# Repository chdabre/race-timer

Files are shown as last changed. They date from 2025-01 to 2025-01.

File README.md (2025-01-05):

# ESP32 7-Segment Race Timer

[][cc-by-sa]

## Overview

A race timing system built with an ESP32-S3 microcontroller and LED display that measures elapsed time between start and finish sensors.

The connection box can provide power to multiple timer modules, and provides a reset button to reset all modules at once.

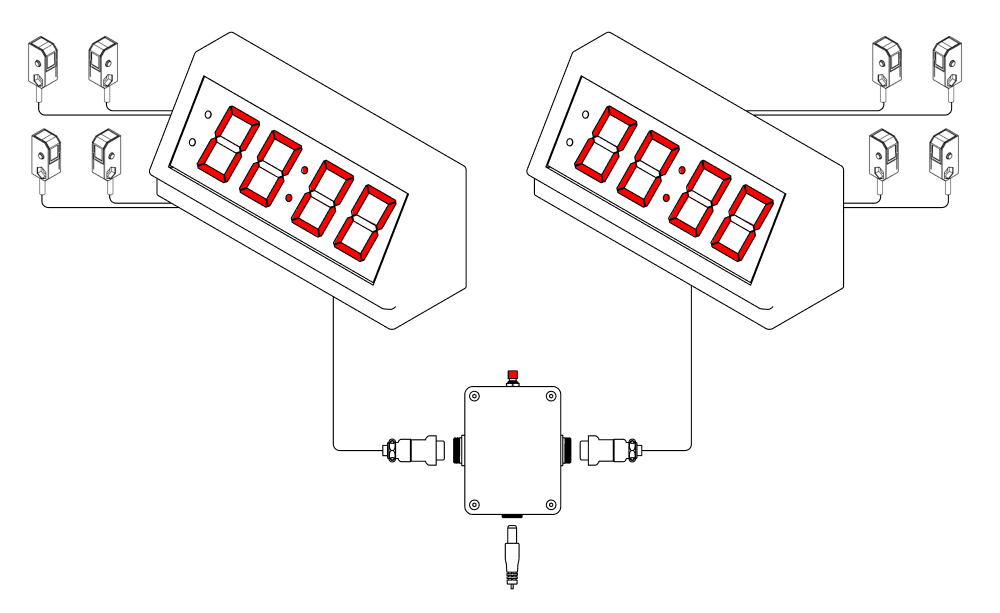
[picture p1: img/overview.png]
Timer Module


The system is designed to be easy to use and assemble. The timer modules are designed to be mounted to a table, and all wiring is run underneath the table.

The timer modules are connected to the connection box with a removable connector, so each module can be transported individually.

If more than 2 modules are needed, the connection box can be easily extended with additional connectors.

## Operation

Two light barriers are connected to each timer module, each consisting of a transmitter and receiver.

The START barrier is mounted at the beginning of the race track.
The STOP barrier is mounted at the end of the race track.

When the START barrier is interrupted, the current time measurement is reset and a new timing begins.

When the STOP barrier is interrupted while timing is active, the timing stops and the final time is shown on the display.

If a timing measurement exceeds 100 seconds, the time can no longer be fully displayed. The seconds display resets to 00: and timing continues.

When the RESET button is pressed at any time, the current timing is stopped and the display immediately resets to 00:00.

## Firmware development and flashing

The firmware is developed using the Arduino Platform on PlatformIO. The project is configured for the Adafruit ESP32-S3 Feather board.

### Dependencies

The following libraries are required and will be automatically installed by PlatformIO:

- Wire
- Adafruit LED Backpack Library

### Building and Flashing

1. Install VS Code and the PlatformIO extension
2. Clone this repository
3. Open the project folder in VS Code
4. Connect the Feather Board via USB
5. Click the PlatformIO "Upload" button or press Ctrl+Alt+U

The serial monitor can be opened at 115200 baud to view debug messages.

## Schematics

See also the KiCad project in the `hardware` folder.

**FeatherWing Schematic**
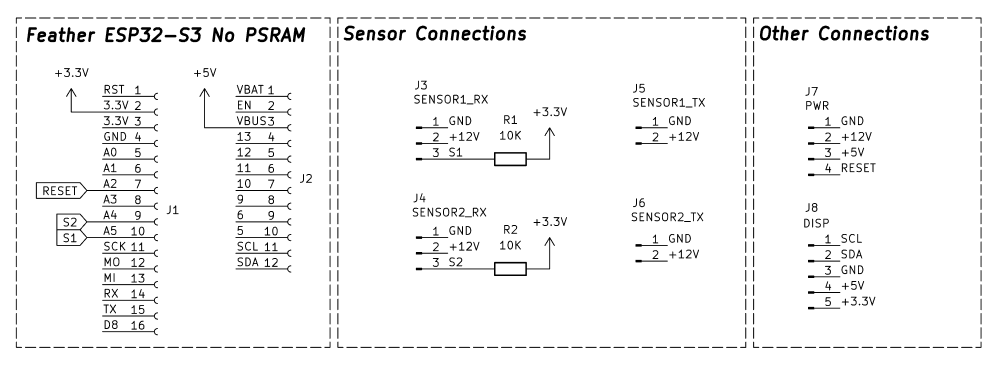
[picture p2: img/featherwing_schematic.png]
Schematic


**Connection Box Schematic**
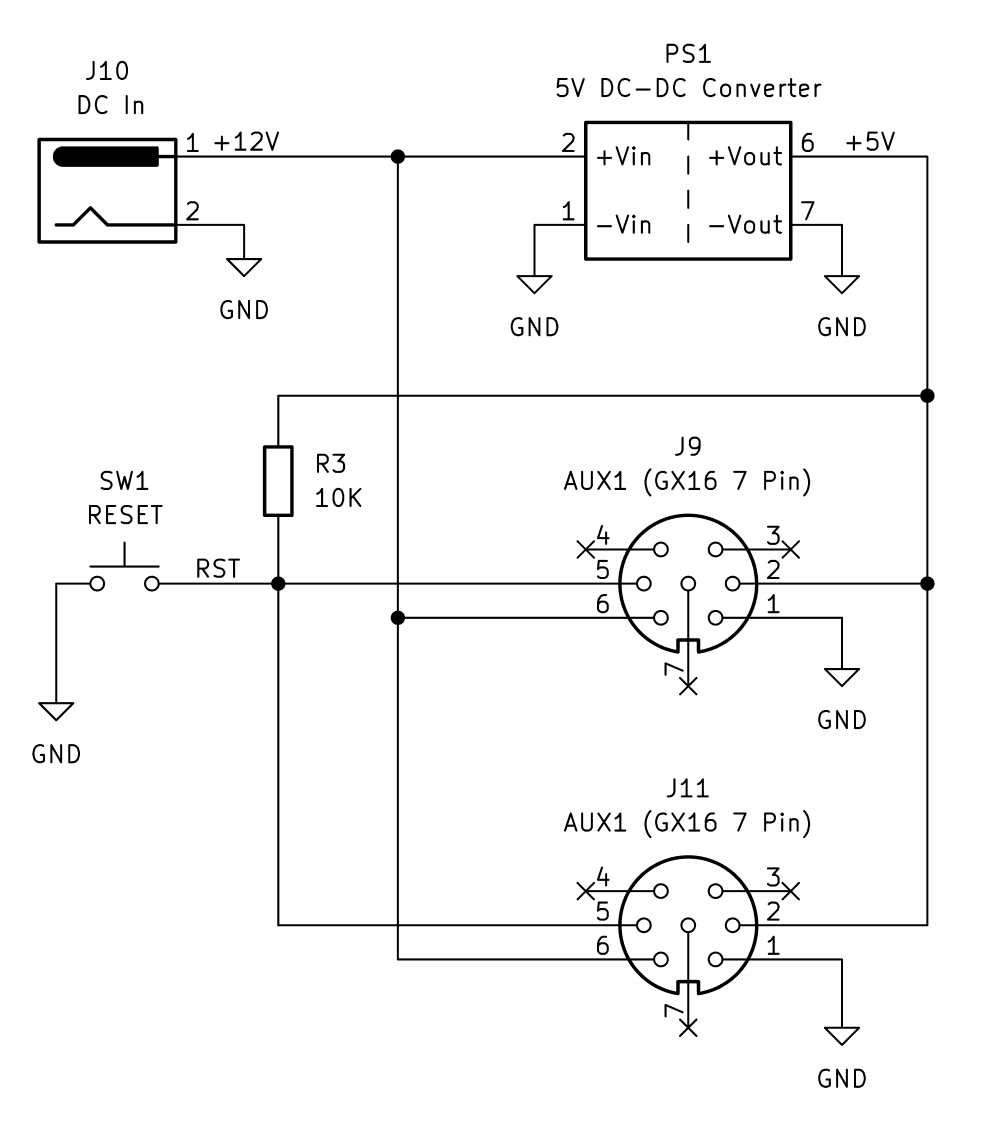
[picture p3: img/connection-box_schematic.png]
Connection Box Schematic


## Bill of Materials

**Per Timer Module**

- 1x 3d printed enclosure (See hardware folder)
- 4x M3 5mm threaded inserts
- 4x M4x6mm threaded inserts
- 4x M3x8mm hex screws
- 4x M4 mounting bolts
- 1x Adafruit ESP32-S3 Feather board (No PSRAM)
- 2x DFRobot Infrared Light Barrier Kit ([SEN0347](https://www.dfrobot.com/product-2057.html))
- 1x Race Timer FeatherWing (See hardware folder)
    - 1x Race Timer FeatherWing PCB 
    - 2x 16-Pin 2.54mm pin headers
    - 1x 5-Pin 2.54mm pin header
    - 2x JST-XH 2.50mm B2B (2-Pin)
    - 2x JST-XH 2.50mm B3B (3-Pin)
    - 1x JST-XH 2.50mm B4B (4-Pin)
    - 2x 10K 1/4W THT Resistor
- 2x JST-XH 2.50mm B2B (2-Pin) Female Connector
- 2x JST-XH 2.50mm B3B (3-Pin) Female Connector
- 1x JST-XH 2.50mm B4B (4-Pin) Female Connector
- 1x GX16 7-Pin Female Connector
- 4-core 20AWG cable to the connection box

**Connection Box**

- 1x 3d printed enclosure (See hardware folder)
- 4x M3 5mm threaded inserts
- 4x M3x8mm hex screws
- 1x Mini360 DC-DC Converter (or similar) 9-24V to 5V
- 2x GX16 7-Pin Male Connector
- 1x DC00990 Panel mount 5.5x2.1mm barrel jack connector
- 1x Generic 8mm panel mount push button switch
- 1x 12V 1A Power Supply 5.5x2.1mm barrel jack, center positive
- Wires for internal connections

## License

This work is licensed under a
[Creative Commons Attribution-ShareAlike 4.0 International License][cc-by-sa].

[][cc-by-sa]

[cc-by-sa]: http://creativecommons.org/licenses/by-sa/4.0/
[cc-by-sa-image]: https://licensebuttons.net/l/by-sa/4.0/88x31.png
[cc-by-sa-shield]: https://img.shields.io/badge/License-CC%20BY--SA%204.0-lightgrey.svg

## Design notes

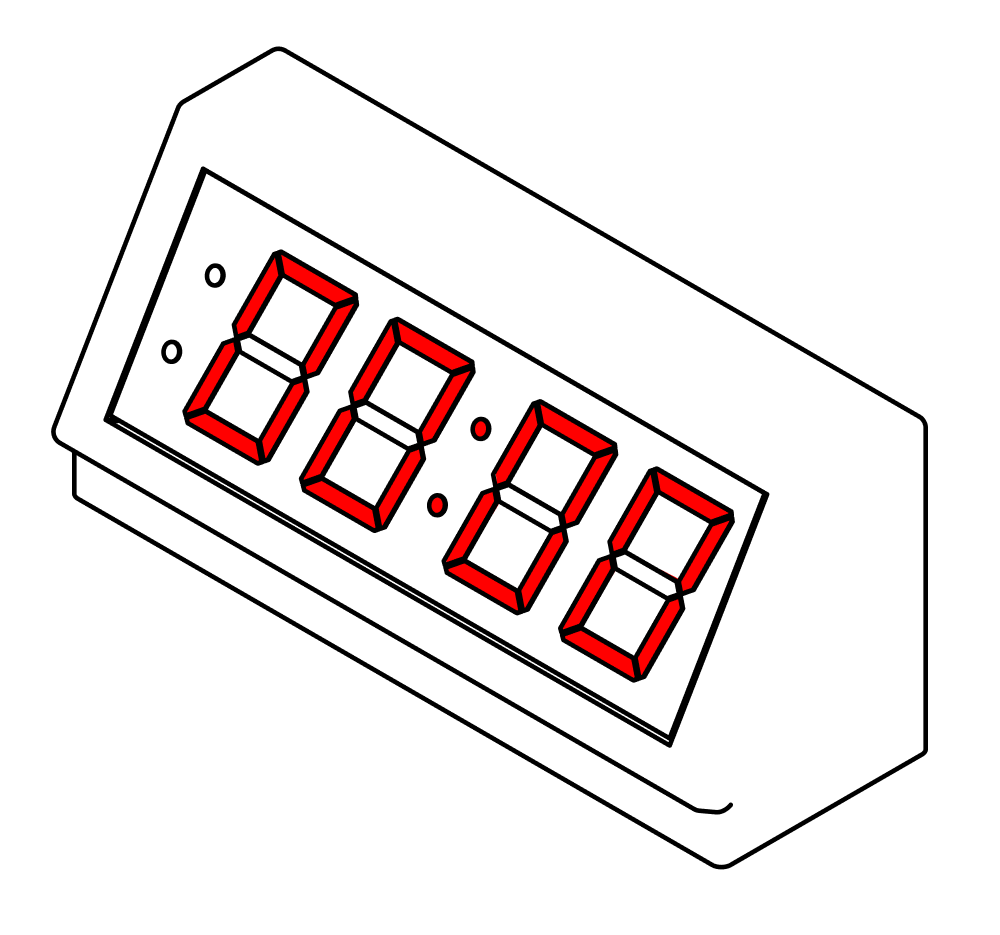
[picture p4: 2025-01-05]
img/timer-module.png

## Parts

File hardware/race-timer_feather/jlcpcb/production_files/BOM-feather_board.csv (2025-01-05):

Comment | Designator | Footprint | LCSC
PWR | J7 | JST_XH_B4B-XH-A_1x04_P2.50mm_Vertical
SENSOR2_TX | J6 | JST_XH_B2B-XH-A_1x02_P2.50mm_Vertical
SENSOR1_TX | J5 | JST_XH_B2B-XH-A_1x02_P2.50mm_Vertical
SENSOR2_RX | J4 | JST_XH_B3B-XH-A_1x03_P2.50mm_Vertical
SENSOR1_RX | J3 | JST_XH_B3B-XH-A_1x03_P2.50mm_Vertical
10K | R2 | R_Axial_DIN0207_L6.3mm_D2.5mm_P10.16mm_Horizontal
10K | R1 | R_Axial_DIN0207_L6.3mm_D2.5mm_P10.16mm_Horizontal
DISP | J8 | PinHeader_1x05_P2.54mm_Vertical
Conn_01x12_Female | J2 | PinSocket_1x12_P2.54mm_Vertical
Conn_01x16_Female | J1 | PinSocket_1x16_P2.54mm_Vertical

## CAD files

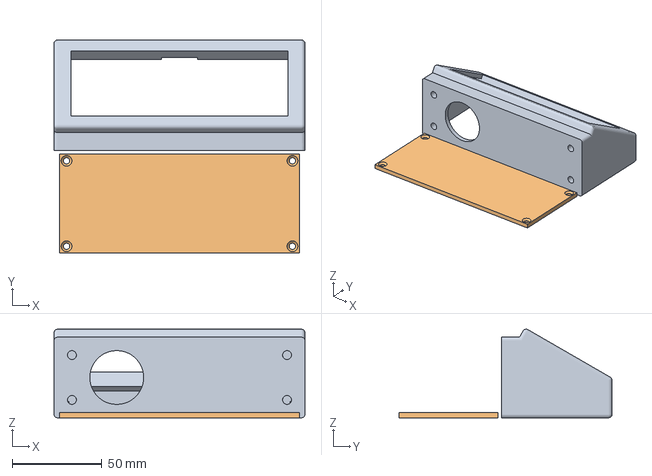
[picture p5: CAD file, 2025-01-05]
hardware/cad/timer-module.3mf
140.0 x 118.9 x 49.5 mm

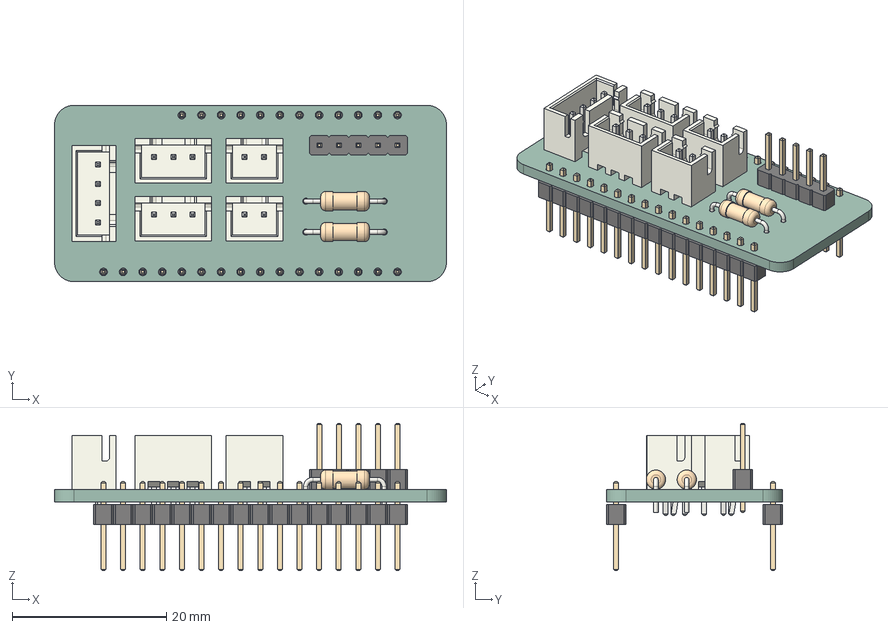
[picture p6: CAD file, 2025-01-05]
hardware/race-timer_feather/race-timer_feather.step
50.8 x 22.9 x 19.1 mm
JST_B2B_XH_A x 2
PinHeader_1x12_P254mm_Vertical
JST_B3B_XH_A x 2
PinHeader_1x05_P254mm_Vertical
R_Axial_DIN0207_L63mm_D25mm_P1016mm_Horizontal x 2
JST_B4B_XH_A
PinHeader_1x16_P254mm_Vertical
feather_board_PCB

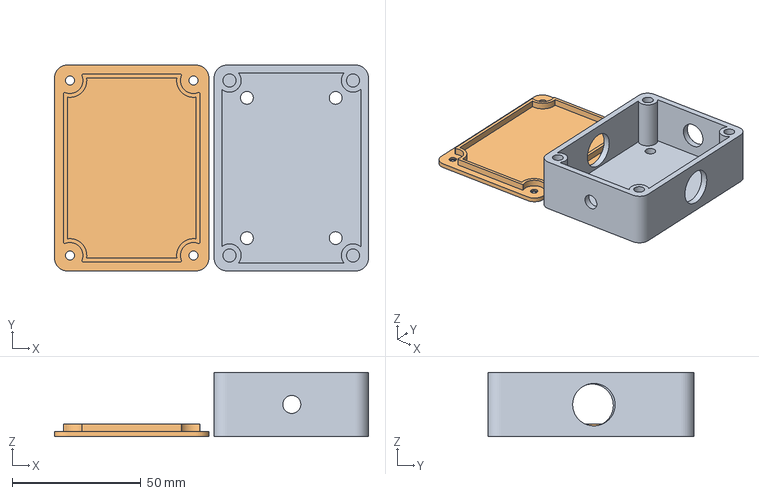
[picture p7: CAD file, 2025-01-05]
hardware/cad/connection-box.3mf
122.0 x 80.0 x 25.0 mm

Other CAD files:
hardware/cad/connection-box.f3z
hardware/cad/timer-module.f3z

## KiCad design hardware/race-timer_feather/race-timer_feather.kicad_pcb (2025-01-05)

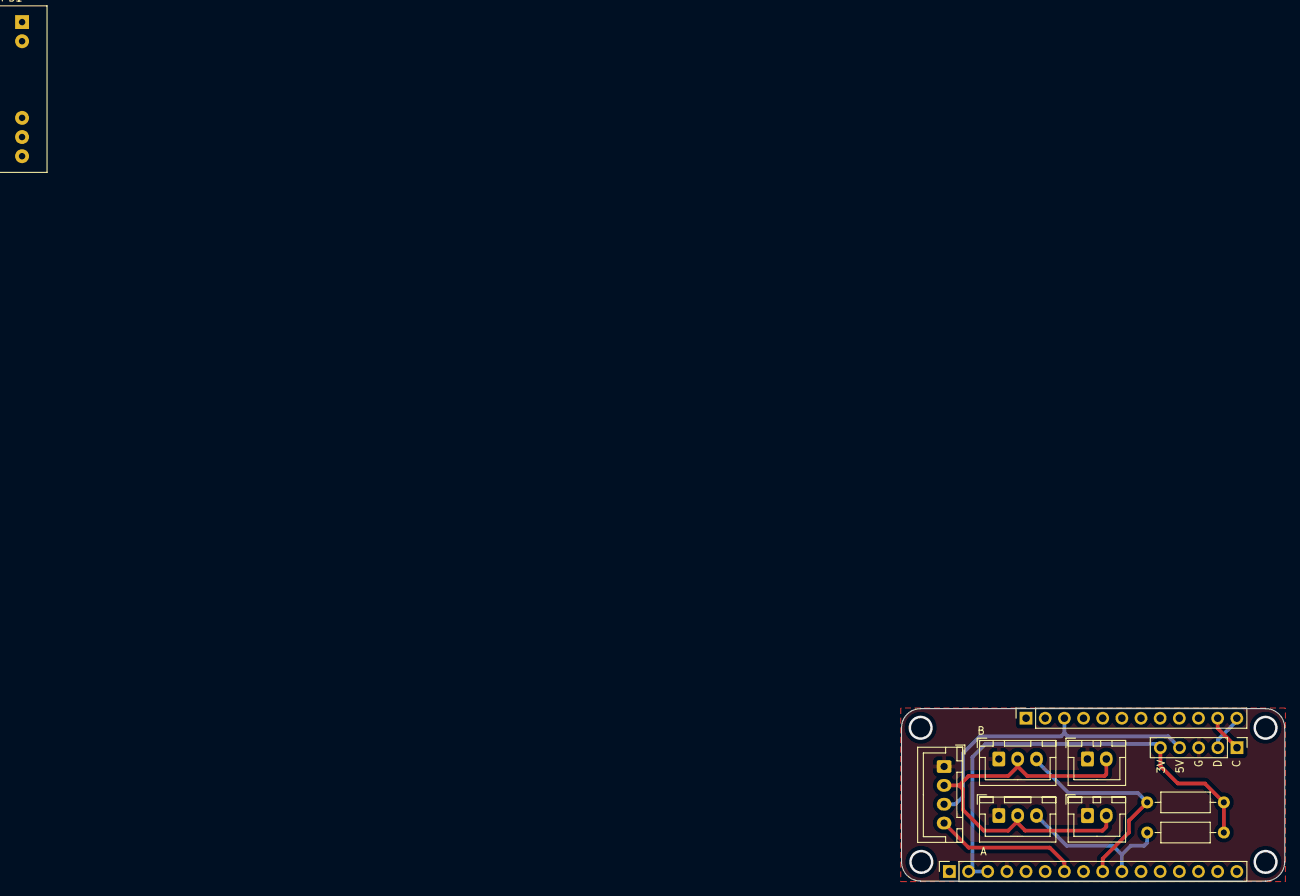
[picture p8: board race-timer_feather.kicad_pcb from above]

Board: 2 copper layers, 50.8 x 22.9 mm, 11 parts (0 on the bottom side), 10 nets.

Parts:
J1: PinSocket_1x16_P2.54mm_Vertical
J2: PinSocket_1x12_P2.54mm_Vertical
J3: SENSOR1_RX; JST_XH_B3B-XH-A_1x03_P2.50mm_Vertical
J4: SENSOR2_RX; JST_XH_B3B-XH-A_1x03_P2.50mm_Vertical
J5: SENSOR1_TX; JST_XH_B2B-XH-A_1x02_P2.50mm_Vertical
J6: SENSOR2_TX; JST_XH_B2B-XH-A_1x02_P2.50mm_Vertical
J7: PWR; JST_XH_B4B-XH-A_1x04_P2.50mm_Vertical
J8: DISP; PinHeader_1x05_P2.54mm_Vertical
PS1: 5V DC-DC Converter; Converter_DCDC_XP_POWER-ITXxxxxSA_THT
R1, R2: 10K; R_Axial_DIN0207_L6.3mm_D2.5mm_P10.16mm_Horizontal

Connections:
+3.3V: J1.2, J1.3, J8.5, R1.2, R2.2
+5V: J2.3, J7.3, J8.4
/+12V: J3.2, J4.2, J5.2, J6.2, J7.2
/GND: J1.4, J3.1, J4.1, J5.1, J6.1, J7.1, J8.3
/SCL: J2.11, J8.1
/SDA: J2.12, J8.2
GND: PS1.1 (-Vin), PS1.7 (-Vout)
RESET: J1.7, J7.4
S1: J1.10, J3.3, R1.1
S2: J1.9, J4.3, R2.1

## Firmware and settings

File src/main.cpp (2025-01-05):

#include <Arduino.h>
#include <Wire.h>
#include <Adafruit_GFX.h>
#include "Adafruit_LEDBackpack.h"

#define RESET_PIN A2
#define SENSOR_START_PIN A5
#define SENSOR_END_PIN A4
#define DEBOUNCE_TIME 50 // 50ms debounce

Adafruit_7segment matrix = Adafruit_7segment();

// Timer state variables
uint32_t race_start_time = 0;
uint32_t race_end_time = 0;
uint32_t race_duration = 0;
bool race_in_progress = false;

// Debounce variables
uint32_t last_reset_time = 0;
uint32_t last_start_time = 0;
uint32_t last_end_time = 0;
bool last_reset_state = HIGH;
bool last_start_state = HIGH;
bool last_end_state = HIGH;

void show_time_ms(uint32_t time_ms)
{
  uint32_t seconds = time_ms / 1000;

  matrix.writeDigitNum(0, (seconds % 100) / 10);
  matrix.writeDigitNum(1, seconds % 10);
  matrix.writeDigitNum(3, (time_ms % 1000) / 100);
  matrix.writeDigitNum(4, (time_ms % 100) / 10);

  matrix.drawColon(true);
  matrix.writeDisplay();
}

void setup()
{
  Serial.begin(115200);
  Serial.println("Race Timer Ready");

  matrix.begin(0x70);
  matrix.setBrightness(15);

  pinMode(RESET_PIN, INPUT_PULLUP);
  pinMode(SENSOR_START_PIN, INPUT_PULLUP);
  pinMode(SENSOR_END_PIN, INPUT_PULLUP);
  digitalWrite(SENSOR_START_PIN, HIGH);
}

void loop()
{
  uint32_t current_time = millis();

  // Read all inputs
  bool reset_state = digitalRead(RESET_PIN);
  bool start_state = digitalRead(SENSOR_START_PIN);
  bool end_state = digitalRead(SENSOR_END_PIN);

  // Handle reset button with debounce
  if (reset_state != last_reset_state && (current_time - last_reset_time) > DEBOUNCE_TIME)
  {
    if (reset_state == LOW)
    { // Button pressed
      race_in_progress = false;
      race_end_time = 0;
      race_start_time = 0;
      race_duration = 0;
    }
    last_reset_time = current_time;
    last_reset_state = reset_state;
  }

  // Handle start sensor with debounce
  if (start_state != last_start_state && (current_time - last_start_time) > DEBOUNCE_TIME)
  {
    if (start_state == LOW)
    { // Sensor triggered
      race_start_time = current_time;
      race_end_time = 0;
      race_duration = 0;
      race_in_progress = true;
    }
    last_start_time = current_time;
    last_start_state = start_state;
  }

  // Handle end sensor with debounce
  if (end_state != last_end_state && (current_time - last_end_time) > DEBOUNCE_TIME)
  {
    if (end_state == LOW && race_in_progress)
    { // Sensor triggered
      race_end_time = current_time;
      race_duration = race_end_time - race_start_time;
      race_in_progress = false;
    }
    last_end_time = current_time;
    last_end_state = end_state;
  }

  // Update display
  if (race_in_progress)
  {
    show_time_ms(current_time - race_start_time);
  }
  else if (race_end_time > 0)
  {
    show_time_ms(race_end_time - race_start_time);
  }
  else
  {
    show_time_ms(0);
  }
}

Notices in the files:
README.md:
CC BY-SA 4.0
